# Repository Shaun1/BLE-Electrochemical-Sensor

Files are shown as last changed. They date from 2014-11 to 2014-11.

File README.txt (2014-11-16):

---------------	LICENCE:

This work is licensed under the Creative Commons Attribution 4.0 International License. To view a copy of this license, visit http://creativecommons.org/licenses/by/4.0/.

You are free to:

Share — copy and redistribute the material in any medium or format
Adapt — remix, transform, and build upon the material
for any purpose, even commercially.
The licensor cannot revoke these freedoms as long as you follow the license terms.

Terms:

Attribution — You must give appropriate credit, provide a link to the license, and indicate if changes were made. You may do so in any reasonable manner, but not in any way that suggests the licensor endorses you or your use.

No additional restrictions — You may not apply legal terms or technological measures that legally restrict others from doing anything the license permits.

All design files for BLE Electrochemical Sensor are provided as-is.

Please credit Houlihan Engineering & Design / www.hedlabs.com if you reproduce this work or create a derivative work.

---------------	CONTENTS:

BLE Electrochemical Sensor.dch
	(DipTrace Schematic)

BLE Electrochemical Sensor.dip
	(DipTrace Board Layout)

BLE Electrochemical Sensor.asc
	(DipTrace ASCII Schemaitic)

BLE Electrochemical Sensor.pcb
	(P-Cad ASCII Board Layout)

BLE Electrochemical Sensor.pdf
	(PDF Schematic)

BLE ES BOM.csv
	(Bill of Materials)

MFG
	(Folder containing Gerber files, Drill file, and Pick and Place CSV file)

---------------	USE:

These files were created using DipTrace, a powerful and low-cost ECAD system. A non-profit free version of DipTrace can be downloaded at http://www.diptrace.com. If you use a different ECAD system, ASCII files are provided for import to other software packages. 3rd-party conversion utilities may be needed depending on the system you are importing to.

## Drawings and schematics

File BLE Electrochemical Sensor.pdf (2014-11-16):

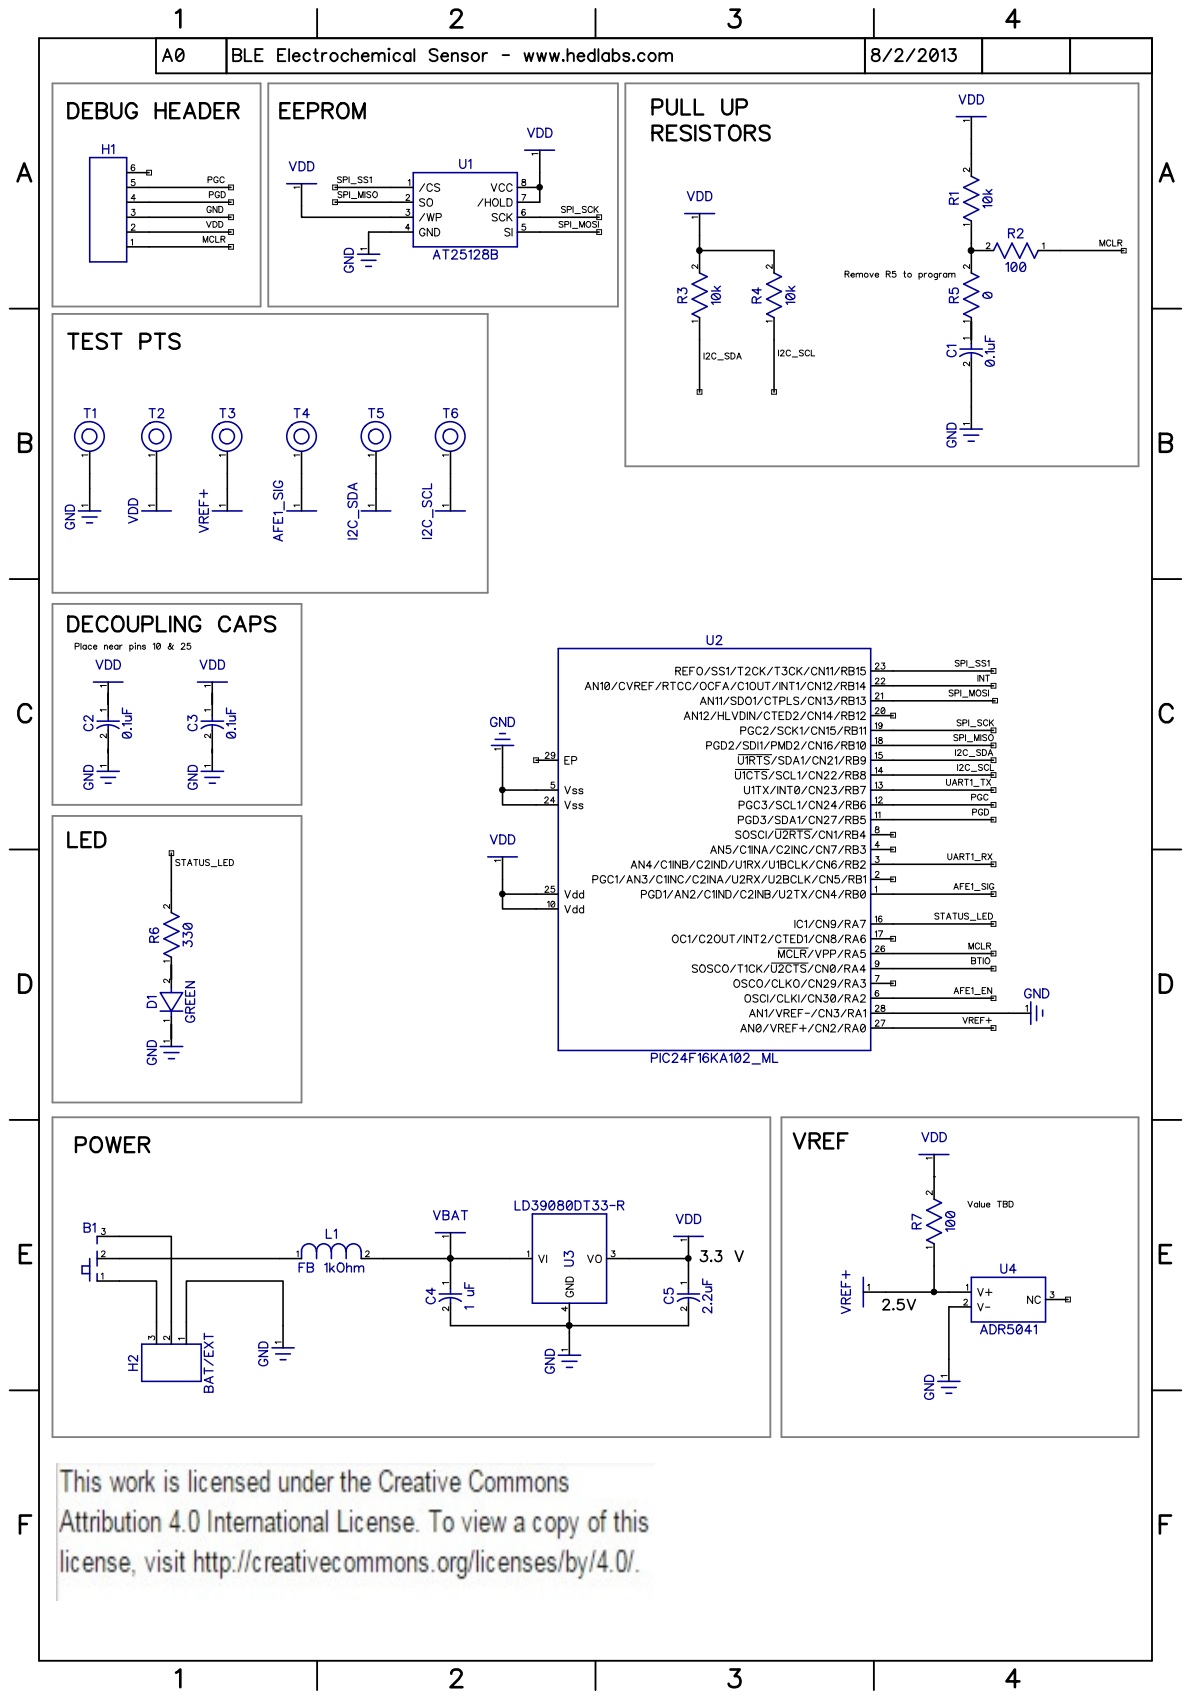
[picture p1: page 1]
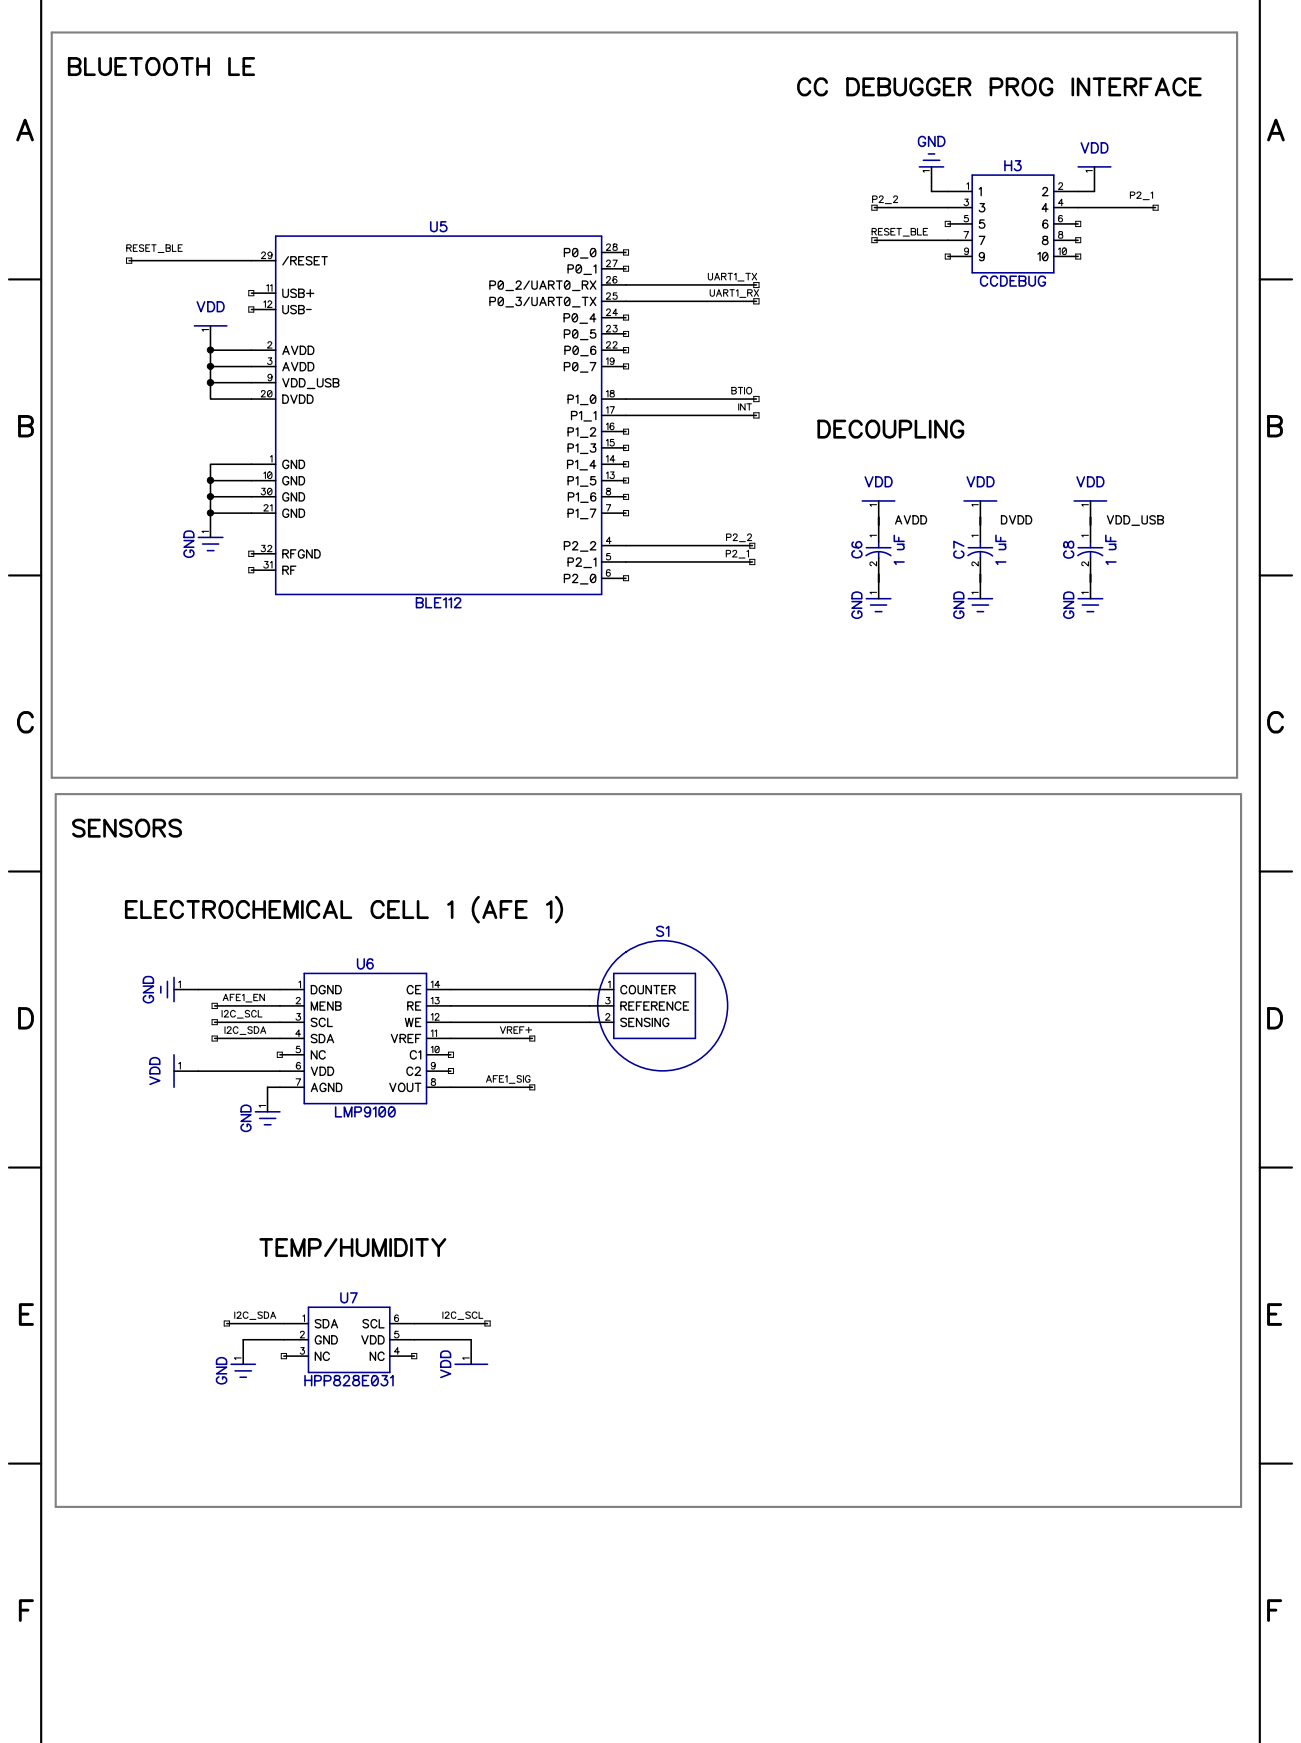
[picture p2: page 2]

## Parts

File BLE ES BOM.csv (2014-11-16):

# | RefDes | Name | Value | Pattern | Quantity | Digikey # | Description
1 | B1 | MLL1200S |  | MLL1200S | 1 | 450-1577-ND | Switch
2 | C1 | CAP_0603 | 0.1uF | CAP_0603 | 1
3 | C2, C3 | CAP_0402 | 0.1uF | CAP_0402 | 2
4 | C4, C6, C7, C8 | CAP_0603 | 1 uF | CAP_0603 | 4
5 | C5 | CAP_0603 | 2.2uF | CAP_0603 | 1
6 | D1 | DIODE_0805 | GREEN | DIO_0805 | 1
7 | H1 | PIC24-DebugHeader |  | SFW6R-2STE1LF | 1 | 609-1890-1-ND | FlatConnector
8 | H2 | 3x1 Pin 1.27 Header |  | 3x1 1.27 | 1
9 | H3 | 5x2 Pin 1.27 Header |  | 5x2 1.27 | 1 |  | CCDEBUG Header
10 | L1 | IND_0804 | FB 1kOhm | IND_0804 | 1
11 | R1, R3, R4 | RES_0603 | 10k | RES_0603 | 3
12 | R2, R7 | RES_0603 | 100 | RES_0603 | 2
13 | R5 | RES_0603 | 0 | RES_0603 | 1
14 | R6 | RES_0603 | 330 | RES_0603 | 1
15 | S1 | R530-0403-02N-440P55-R27-L14 |  | R530-0403-02N-440P55-R27-L14 | 1 |  | SGX Sensor Socket from Andon Electronics
16 | T1, T2, T3, T4, T5, T6 | Test Point |  | NP | 0
17 | U1 | AT25128B |  | SOIC-8/150mil | 1 | AT25128B-SSHL-T | EEPROM
18 | U2 | PIC24F16KA102_ML |  | QFN-28/6x6x0.65 | 1 | PIC24F16KA102-I/ML-ND | MCU
19 | U3 | LD39080DT33-R |  | TO252-3(4)/10x6.6x2.28 | 1 | 497-6015-1-ND | V-reg
20 | U4 | ADR5041 | 2.5V | SOT323 | 1 | ADR5041BKSZ-REEL7CT-ND | 2.5v shunt
21 | U5 | BLE112 |  | BLE112 | 1 | Mouser (603-BLE112-A) | BLE
22 | U6 | LMP9100 |  | LMP91002 | 1 | LMP91002SD/NOPBCT-ND | AFE
23 | U7 | HPP828E031 |  | HTU21D | 1 | 223-1144-1-ND | Temp/Hum
 |  |  |  |  | 35

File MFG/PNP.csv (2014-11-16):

RefDes | Name | X (in) | Y (in) | Side | Rotate | Value
B1 | MLL1200S | 2.581 | 0.951 | Top | 90
C1 | CAP_0603 | 1.163 | 0.142 | Top | 270 | 0.1uF
C2 | CAP_0402 | 1.466 | 0.431 | Top | 270 | 0.1uF
C3 | CAP_0402 | 1.504 | 0.794 | Top | 0 | 0.1uF
C4 | CAP_0603 | 2.144 | 0.792 | Top | 270 | 1 uF
C5 | CAP_0603 | 2.143 | 1.04 | Top | 90 | 2.2uF
C6 | CAP_0603 | 2.552 | 0.678 | Top | 0 | 1 uF
C7 | CAP_0603 | 2.157 | 0.678 | Top | 180 | 1 uF
C8 | CAP_0603 | 1.82 | 0.215 | Top | 270 | 1 uF
D1 | DIODE_0805 | 1.763 | 0.662 | Top | 180 | GREEN
H1 | PIC24-DebugHeader | 1.507 | 0.295 | Top | 0
H2 | 3Pin | 2.384 | 0.926 | Top | 270 | BAT/EXT
H3 | 10 (5x2) Pin | 2.2 | 0.661 | Bottom | 270 | CCDEBUG
L1 | IND_0804 | 2.236 | 0.825 | Top | 180 | FB 1kOhm
R1 | RES_0603 | 1.163 | 0.408 | Top | 90 | 10k
R2 | RES_0603 | 1.279 | 0.375 | Top | 180 | 100
R3 | RES_0603 | 1.721 | 0.45 | Top | 0 | 10k
R4 | RES_0603 | 1.721 | 0.388 | Top | 0 | 10k
R5 | RES_0603 | 1.163 | 0.283 | Top | 90 | 0
R6 | RES_0603 | 1.704 | 0.575 | Top | 180 | 330
R7 | RES_0603 | 1.15 | 0.896 | Top | 90 | 100
S1 | ECHEM SENSOR | 0.41 | 0.6 | Top | 270
U1 | AT25128B | 1.394 | 0.987 | Top | 0
U2 | PIC24F16KA102_ML | 1.491 | 0.623 | Top | 0
U3 | LD39080DT33-R | 1.894 | 0.916 | Top | 180
U4 | ADR5041 | 1.149 | 0.734 | Top | 270 | 2.5V
U5 | BLE112 | 1.898 | 0.363 | Top | 270
U6 | LMP9100 | 0.947 | 0.55 | Top | 0
U7 | HPP828E031 | 0.727 | 1.009 | Top | 270
U8 | LOGO | 0.788 | 0.263 | Top | 0
